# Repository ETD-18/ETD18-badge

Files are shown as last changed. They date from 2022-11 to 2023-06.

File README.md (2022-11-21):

# ETD18-badge
This badge commemorates the ETD18 training group

## Schematic
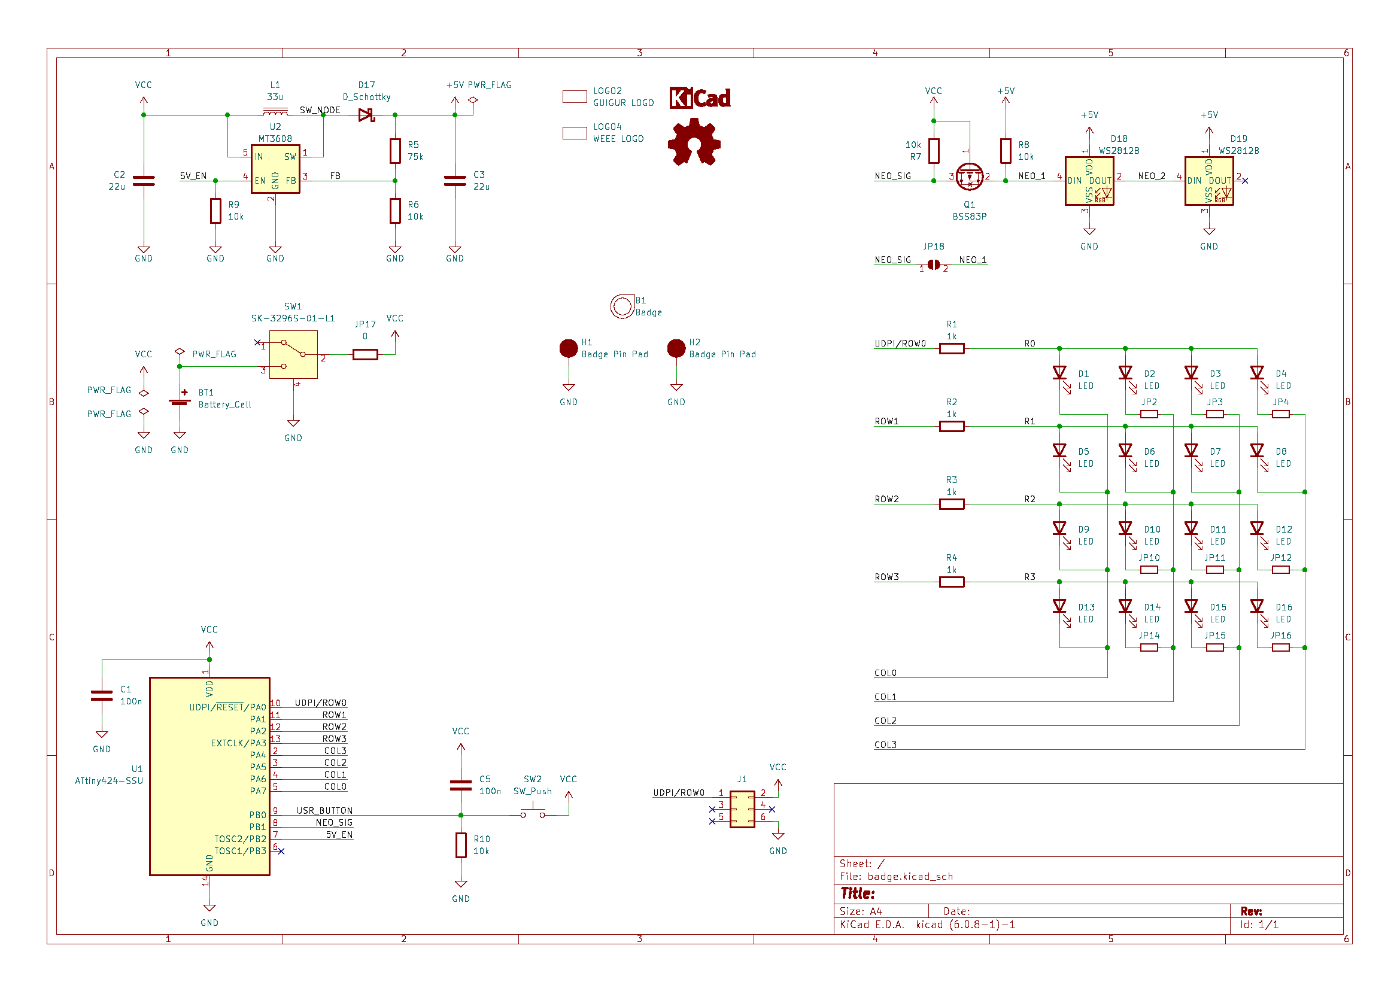
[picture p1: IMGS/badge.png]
schematic schematic of the badge


## Pics
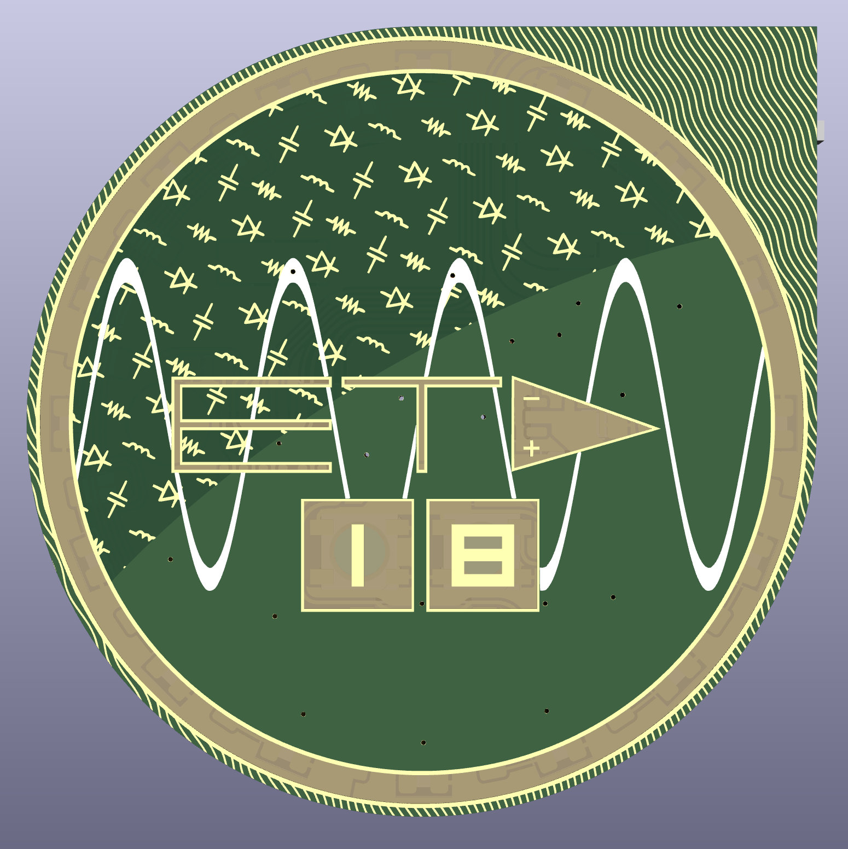
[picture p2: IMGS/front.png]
front front of the badge

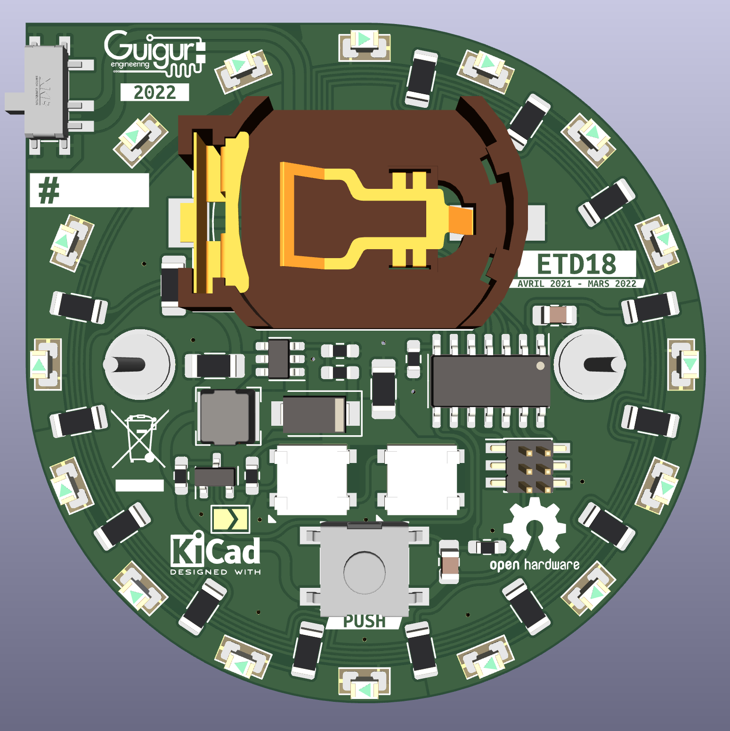
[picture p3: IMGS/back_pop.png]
back back of the badge


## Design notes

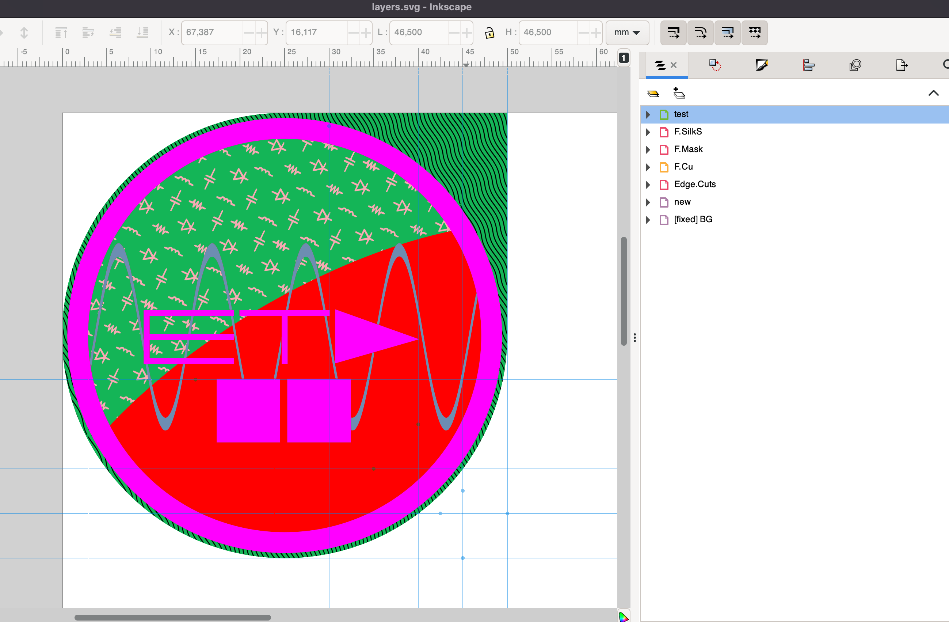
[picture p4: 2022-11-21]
IMGS/inkscape.png

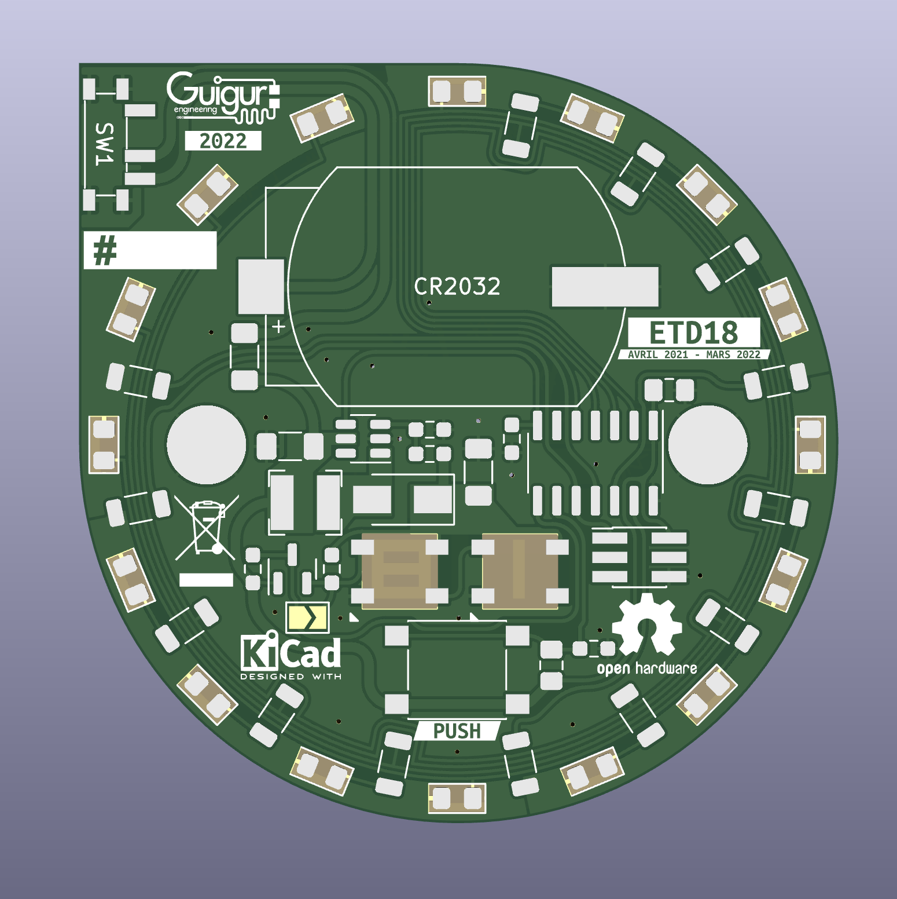
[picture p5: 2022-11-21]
IMGS/back.png

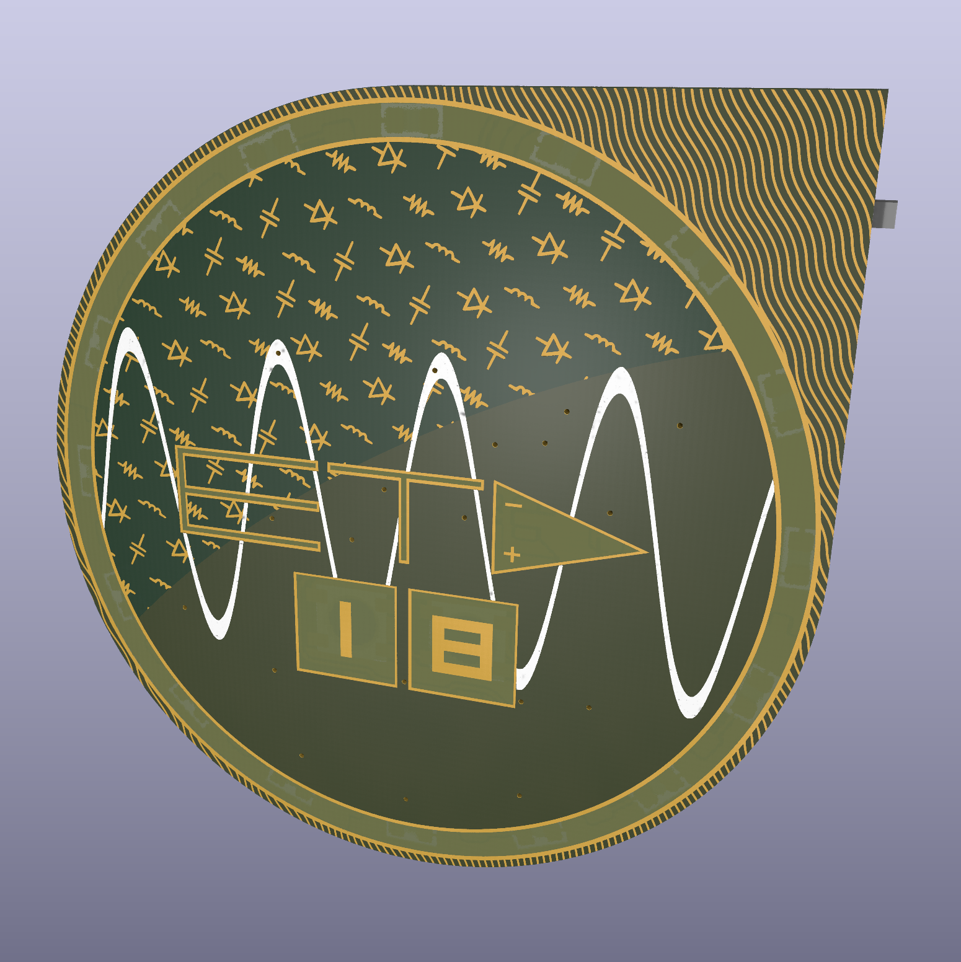
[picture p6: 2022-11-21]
IMGS/front_iso_rayt.png

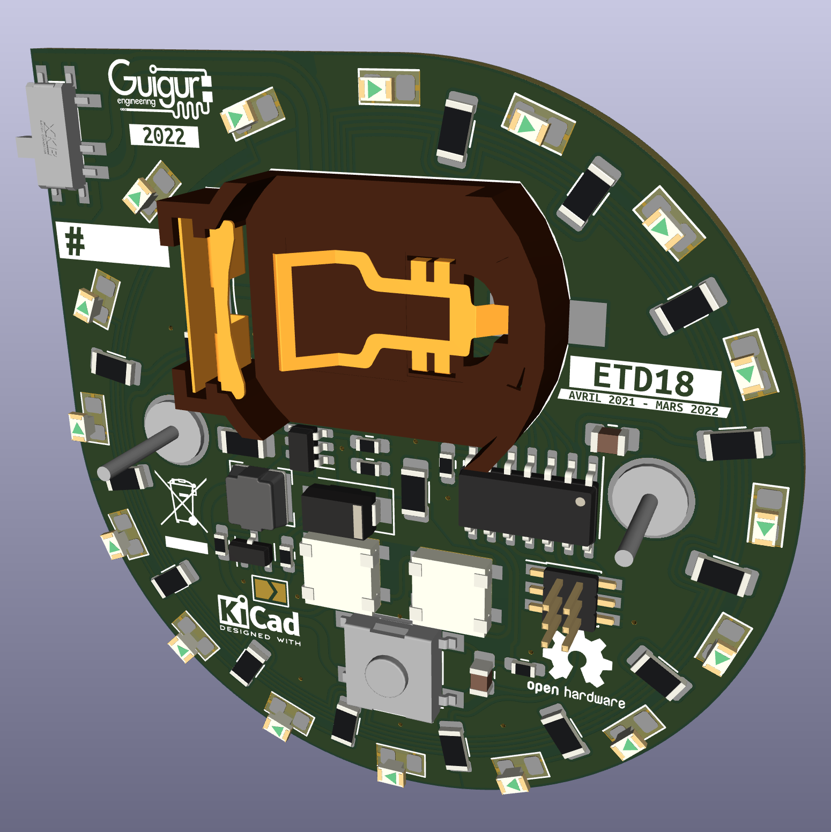
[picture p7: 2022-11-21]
IMGS/back_pop_iso.png

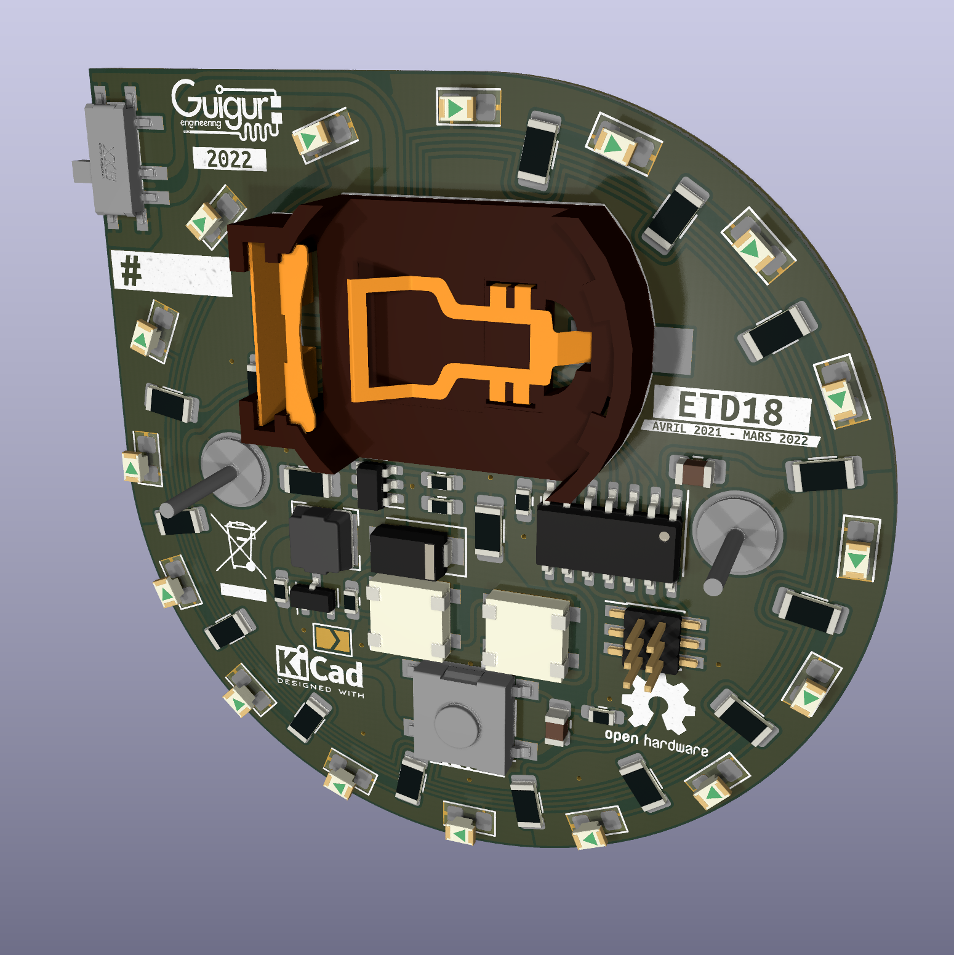
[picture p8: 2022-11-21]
IMGS/back_pop_iso_rayt.png

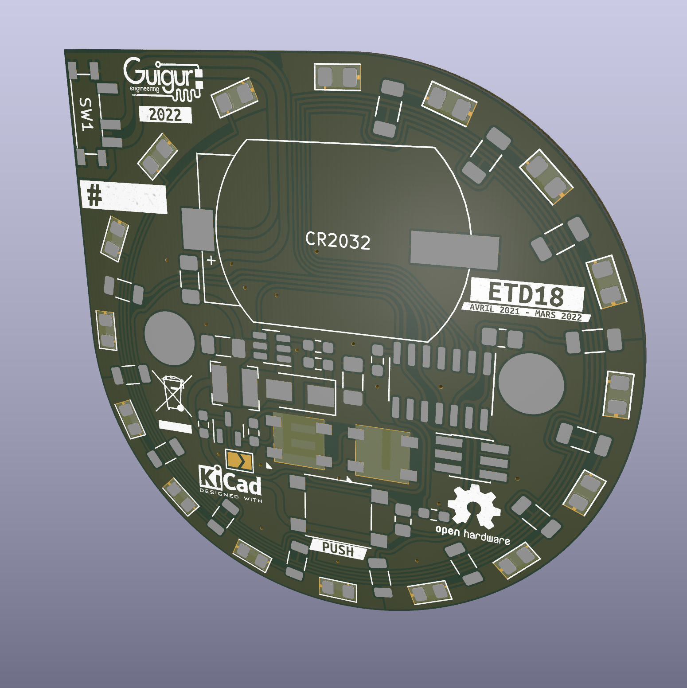
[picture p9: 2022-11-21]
IMGS/back_iso_rayt.png

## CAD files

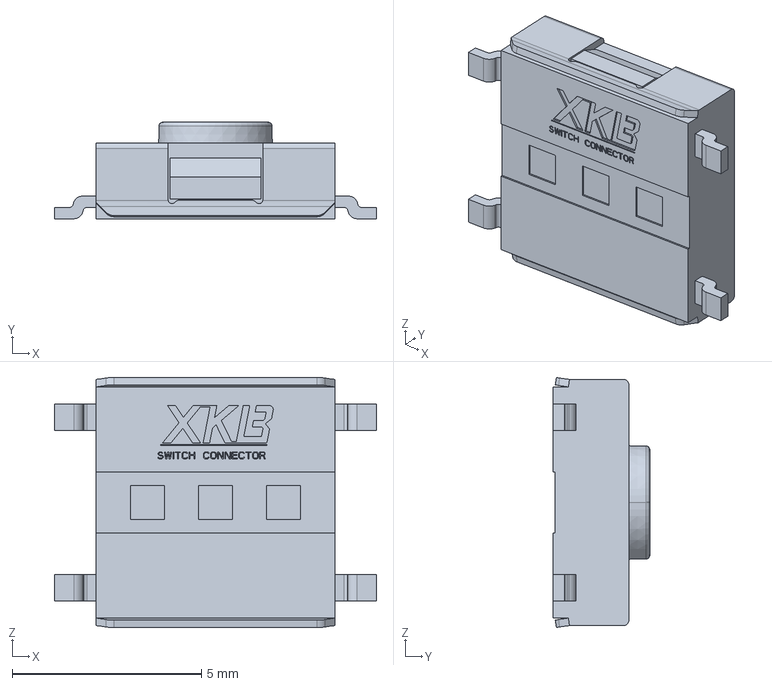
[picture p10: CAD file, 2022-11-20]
badge/step/ts-1157-b-a.stp
8.50 x 2.55 x 6.60 mm

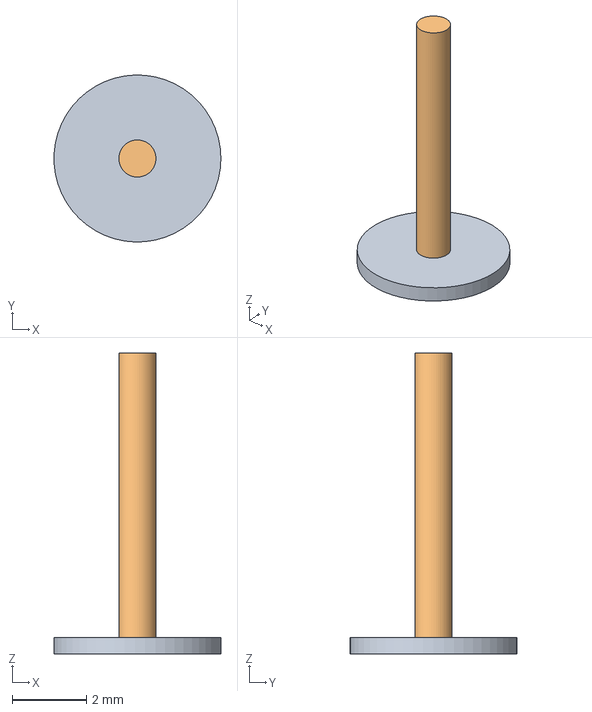
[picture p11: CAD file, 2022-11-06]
badge/step/pin.step
4.50 x 4.50 x 8.11 mm

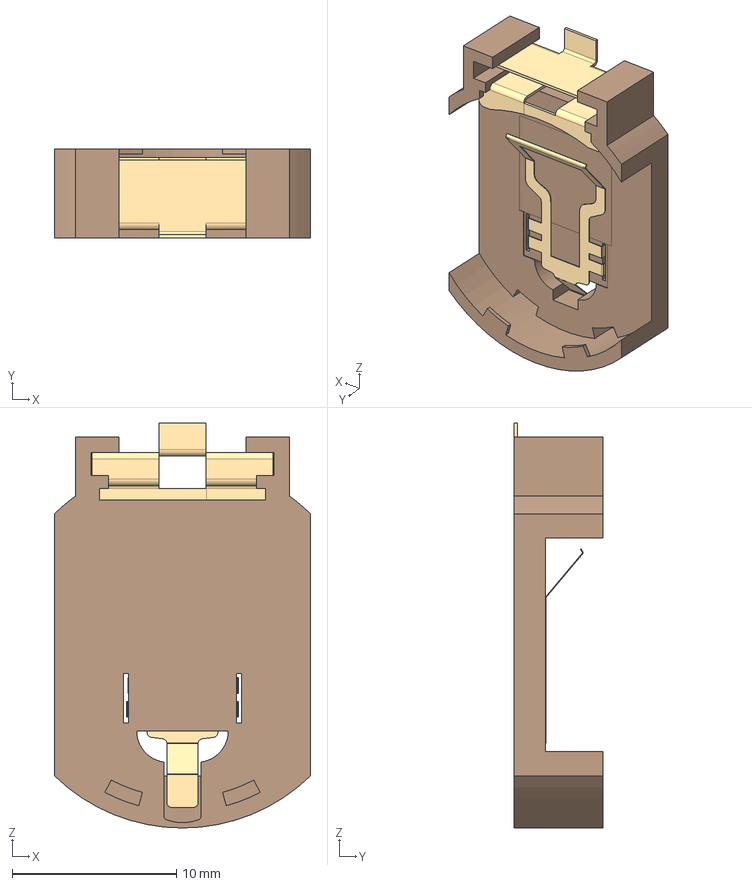
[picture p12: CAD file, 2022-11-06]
badge/step/s8421-45r.stp
15.6 x 5.40 x 24.7 mm

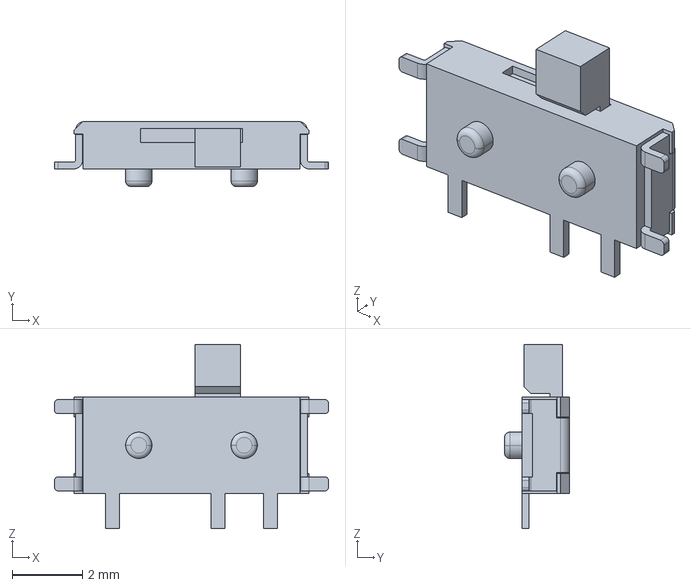
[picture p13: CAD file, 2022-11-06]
badge/step/sk-3296s-01-l1.stp
7.80 x 1.85 x 5.25 mm

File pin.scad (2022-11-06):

cylinder( r = 2.25, h=0.45 );
cylinder( r = 0.5, h=8.11 );

// Written by Marius Kintel <marius@kintel.net>
//
// To the extent possible under law, the author(s) have dedicated all
// copyright and related and neighboring rights to this software to the
// public domain worldwide. This software is distributed without any
// warranty.
//
// You should have received a copy of the CC0 Public Domain
// Dedication along with this software.
// If not, see <http://creativecommons.org/publicdomain/zero/1.0/>.

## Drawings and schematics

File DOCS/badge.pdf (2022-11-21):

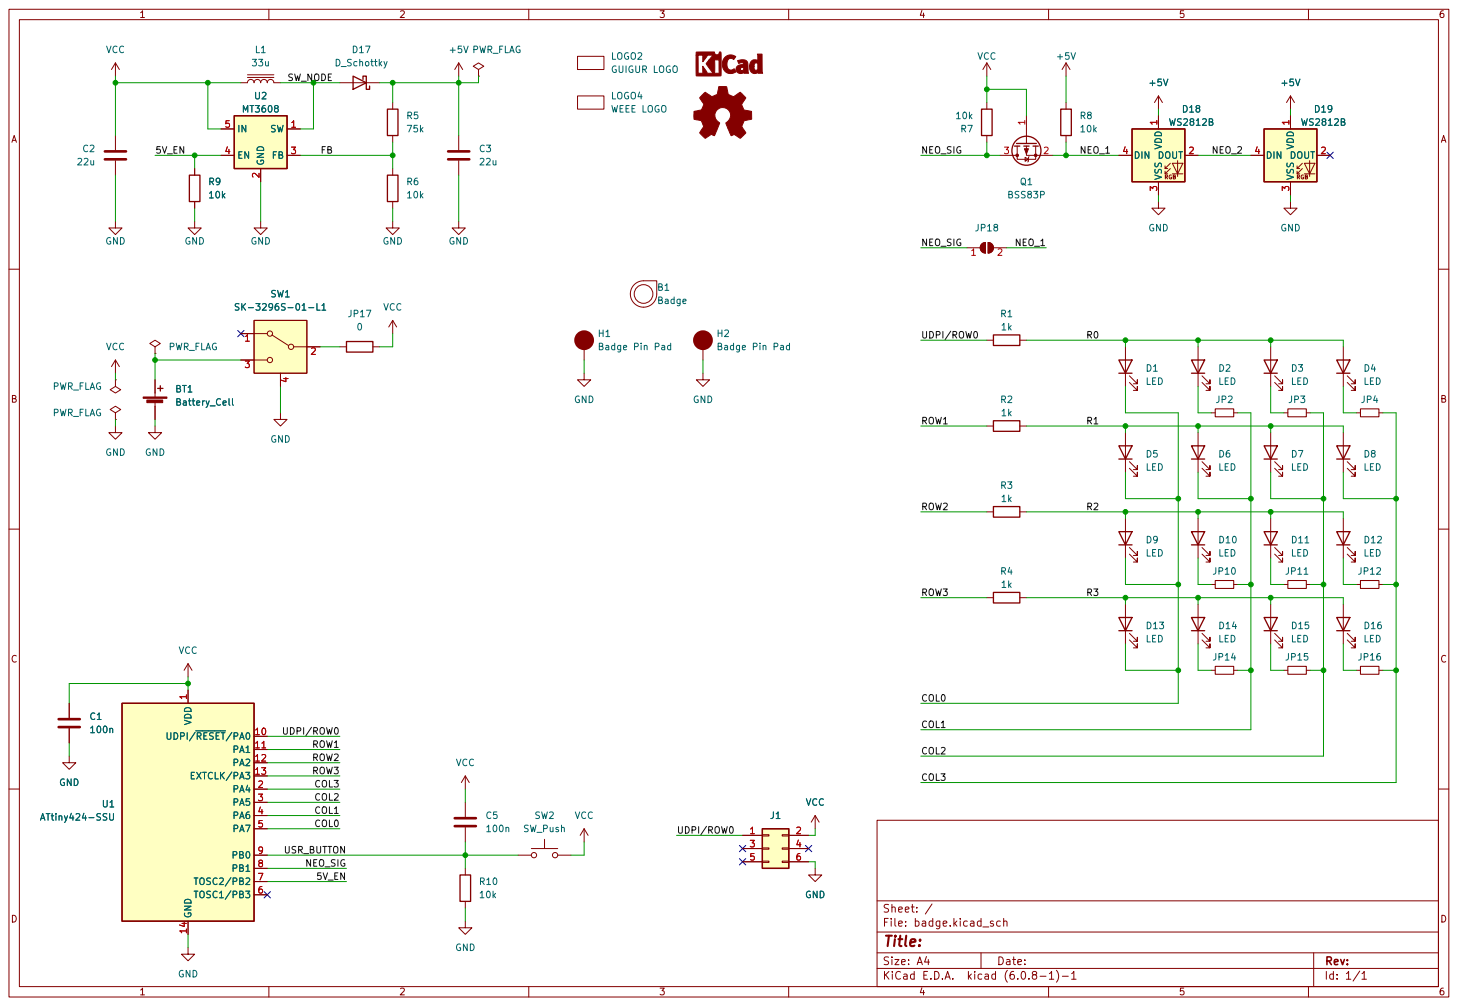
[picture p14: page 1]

1k H2Badge Pin Pad GND GND

1 UDPI/~{RESET}/PA010 PA1 11 PA2 12 EXTCLK/PA3 13 GND 14 PA4 2 PA5 3 PA6 4 PA7 5 TOSC1/PB3 6 TOSC2/PB2 7 PB1 8 PB0 9 GND

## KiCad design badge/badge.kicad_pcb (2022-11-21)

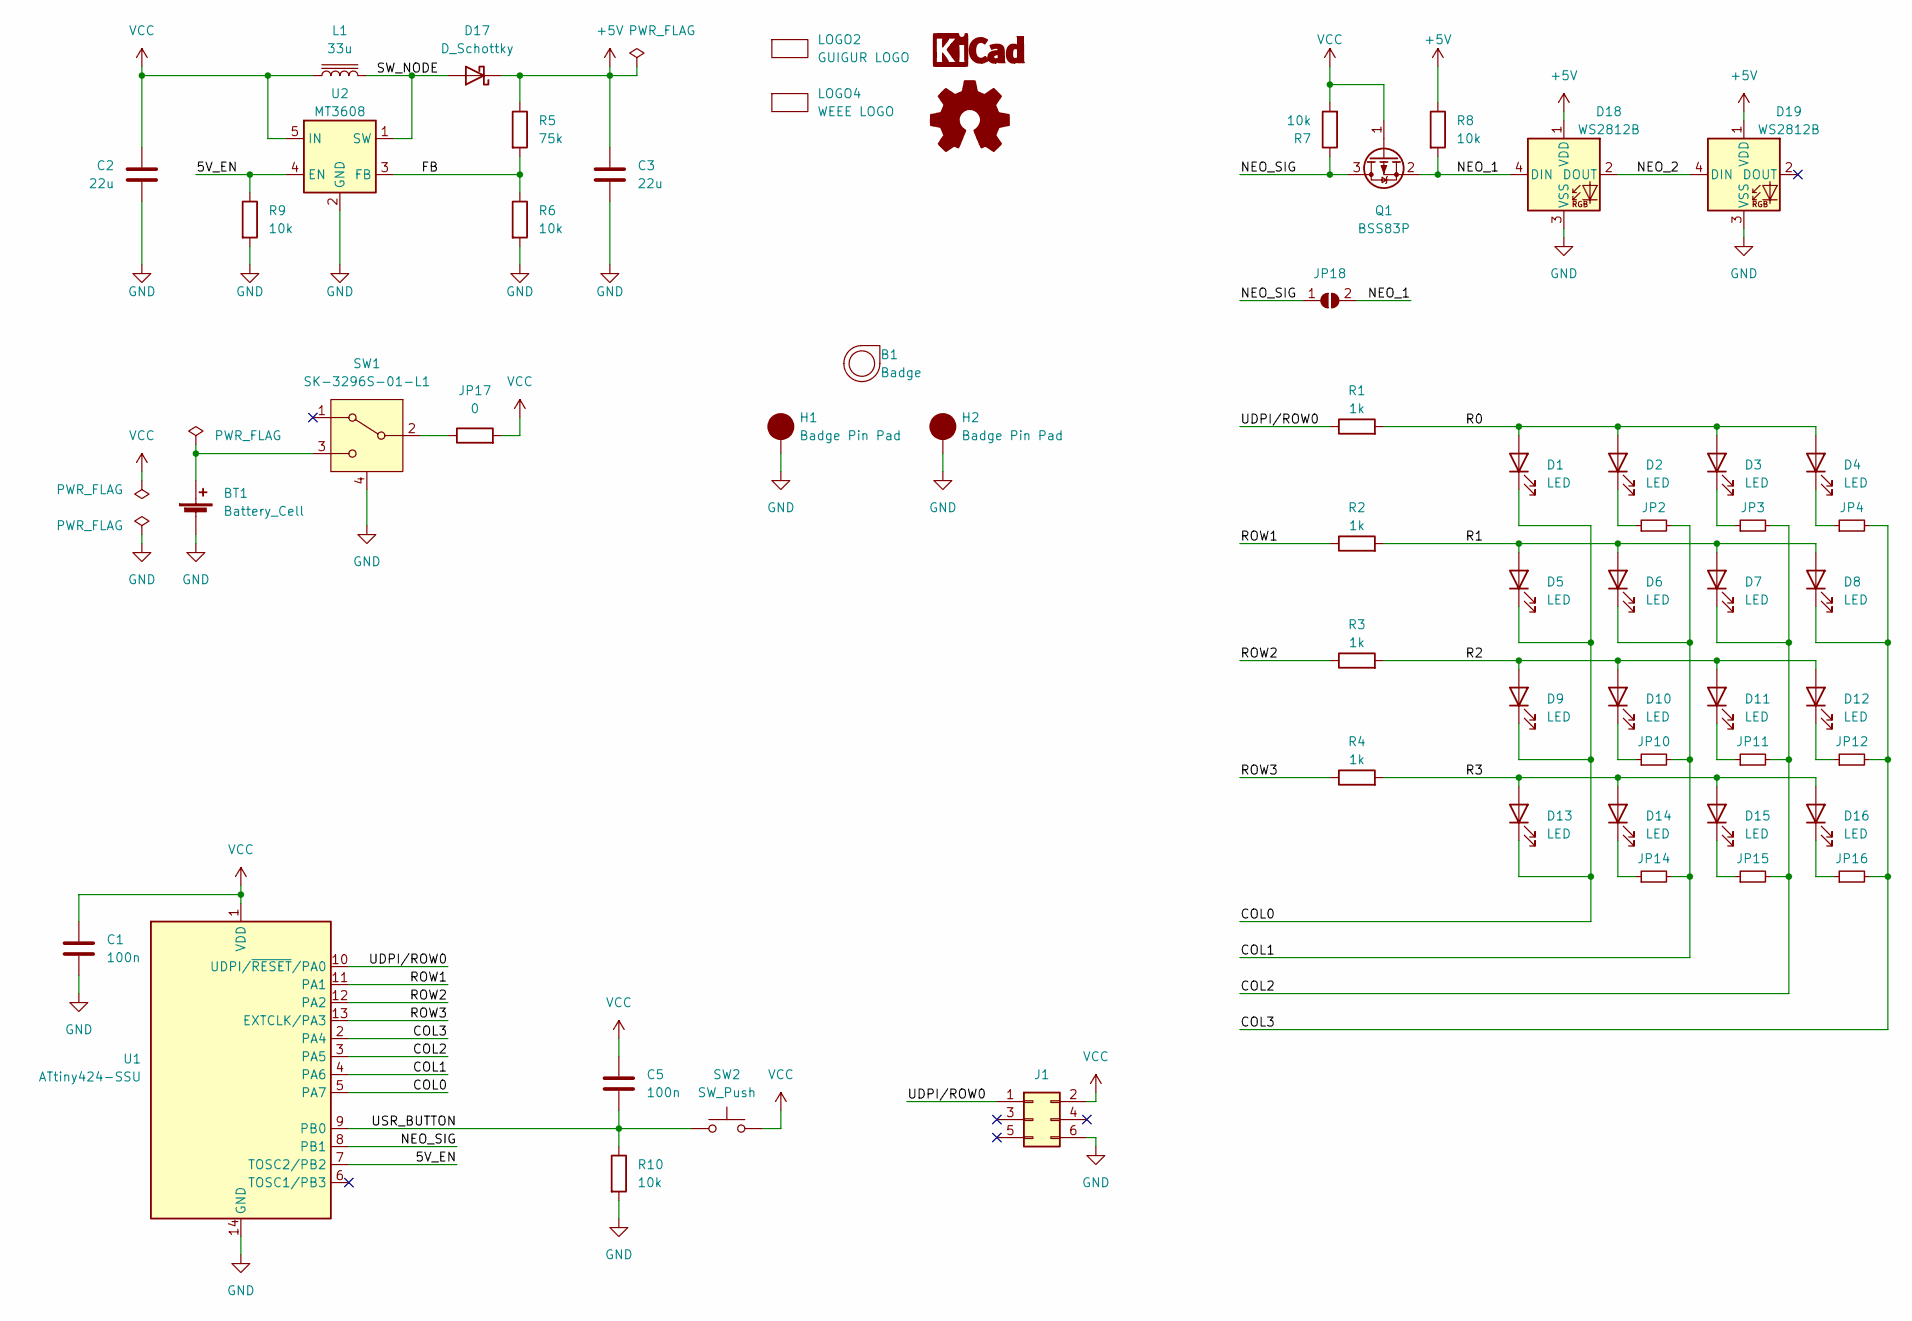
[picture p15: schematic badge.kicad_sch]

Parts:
B1: Badge; layers
BT1: Battery_Cell; cr_2032_holder_S8421-45R
C1, C5: 100n; C_0805_2012Metric_Pad1.18x1.45mm_HandSolder
C2, C3: 22u; R_1206_3216Metric_Pad1.30x1.75mm_HandSolder
D1, D2, D3, D4, D5, D6, D7, D8, D9, D10, D11, D12, D13, D14, D15, D16: LED; LED_0805_2012_badge
D17: D_Schottky; D_SMA
D18, D19: WS2812B; LED_WS2812B_PLCC4_5.0x5.0mm_P3.2mm
H1, H2: Badge Pin Pad; pin_badge
J1: Conn_02x03_Odd_Even; UDPI_connector
JP2, JP3, JP4, JP10, JP11, JP12, JP14, JP15, JP16: 0; R_1206_3216_jumper
JP17: 0; R_1206_3216Metric_Pad1.30x1.75mm_HandSolder
JP18: SolderJumper_2_Open; SolderJumper-2_P1.3mm_Open_TrianglePad1.0x1.5mm
L1: 33u; L_Bourns-SRN4018
LOGO1: Logo_Open_Hardware_Small; OSHW-Logo2_7.3x6mm_SilkScreen
LOGO2: GUIGUR LOGO; guigur_engineering_extra_small_logo
LOGO3: KiCAD LOGO Small; kicad_design_with_7.5mm
LOGO4: WEEE LOGO; WEEE-Logo_4.2x6mm_SilkScreen
Q1: BSS83P; SOT-23
R1, R2, R3, R4: 1k; R_1206_3216_jumper
R5: 75k; R_0603_1608Metric_Pad0.98x0.95mm_HandSolder
R6, R7, R8, R9, R10: 10k; R_0603_1608Metric_Pad0.98x0.95mm_HandSolder
SW1: SK-3296S-01-L1; sk-3296s-01-l1
SW2: SW_Push; SW_Push_1P1T_NO_6x6mm_H9.5mm
U1: ATtiny424-SSU; SOIC-14_3.9x8.7mm_P1.27mm
U2: MT3608; SOT-23-6

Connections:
+5V: C3.1, D17.1 (K), D18.1 (VDD), D19.1 (VDD), R5.1, R8.1
/5V_EN: R9.1, U1.7 (TOSC2/PB2), U2.4 (EN)
/COL0: D1.1 (K), D5.1 (K), D9.1 (K), D13.1 (K), U1.5 (PA7)
/COL1: D6.1 (K), JP2.2, JP10.2, JP14.2, U1.4 (PA6)
/COL2: D7.1 (K), JP3.2, JP11.2, JP15.2, U1.3 (PA5)
/COL3: D8.1 (K), JP4.2, JP12.2, JP16.2, U1.2 (PA4)
/FB: R5.2, R6.1, U2.3 (FB)
/NEO_1: D18.4 (DIN), JP18.2 (B), Q1.2 (S), R8.2
/NEO_2: D18.2 (DOUT), D19.4 (DIN)
/NEO_SIG: JP18.1 (A), Q1.3 (D), R7.1, U1.8 (PB1)
/R0: D1.2 (A), D2.2 (A), D3.2 (A), D4.2 (A), R1.2
/R1: D5.2 (A), D6.2 (A), D7.2 (A), D8.2 (A), R2.2
/R2: D9.2 (A), D10.2 (A), D11.2 (A), D12.2 (A), R3.2
/R3: D13.2 (A), D14.2 (A), D15.2 (A), D16.2 (A), R4.2
/ROW1: R2.1, U1.11 (PA1)
/ROW2: R3.1, U1.12 (PA2)
/ROW3: R4.1, U1.13 (EXTCLK/PA3)
/SW_NODE: D17.2 (A), L1.2, U2.1 (SW)
/UDPI/ROW0: J1.1, R1.1, U1.10 (UDPI/~RESET/PA0)
/USR_BUTTON: C5.2, R10.1, SW2.1, U1.9 (PB0)
GND: BT1.2 (-), C1.2, C2.2, C3.2, D18.3 (VSS), D19.3 (VSS), H1.1, H2.1, J1.6, R6.2, R9.2, R10.2, SW1.4 (CHASSIS), U1.14 (GND), U2.2 (GND)
unnamed: BT1.1 (+), SW1.3 (C)
unnamed: D2.1 (K), JP2.1
unnamed: D3.1 (K), JP3.1
unnamed: D4.1 (K), JP4.1
unnamed: D10.1 (K), JP10.1
unnamed: D11.1 (K), JP11.1
unnamed: D12.1 (K), JP12.1
unnamed: D14.1 (K), JP14.1
unnamed: D15.1 (K), JP15.1
unnamed: D16.1 (K), JP16.1
unnamed: JP17.1, SW1.2 (B)
VCC: C1.1, C2.1, C5.1, J1.2, JP17.2, L1.1, Q1.1 (G), R7.2, SW2.2, U1.1 (VDD), U2.5 (IN)

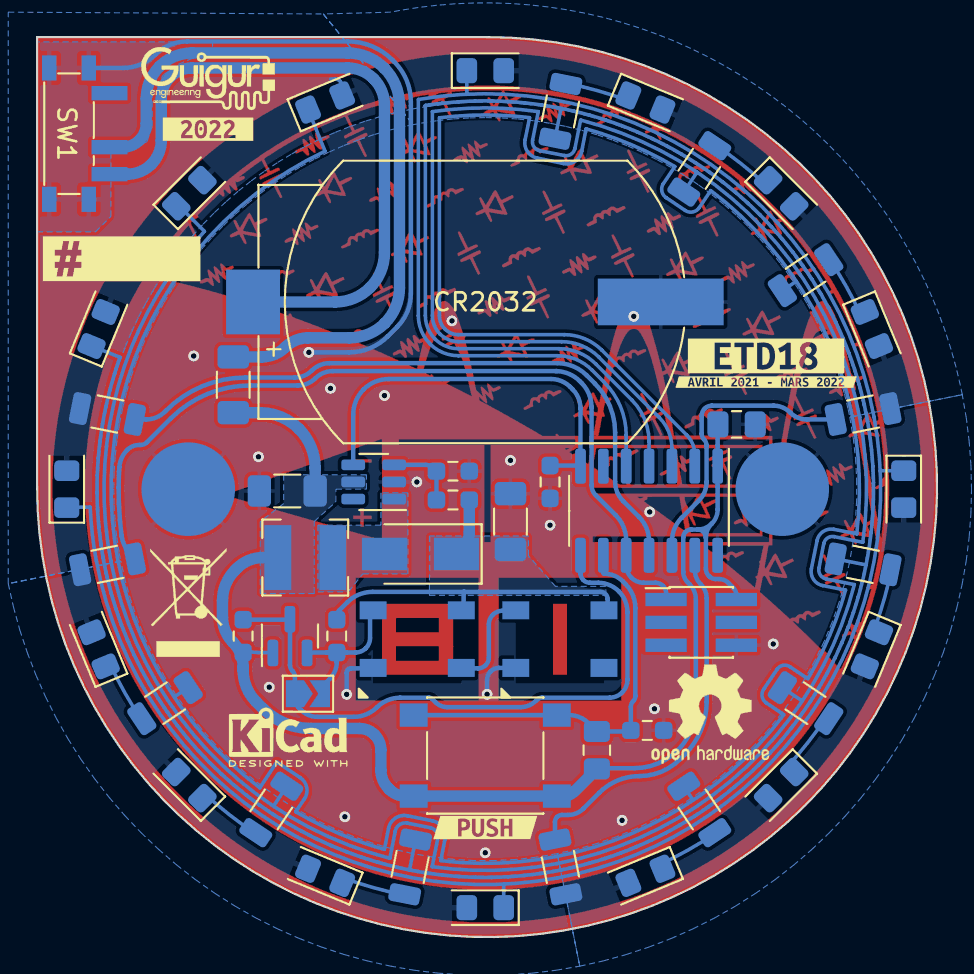
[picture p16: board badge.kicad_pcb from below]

Board: 2 copper layers, 50.0 x 50.0 mm, 64 parts (63 on the bottom side), 33 nets.

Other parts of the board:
kibuzzard-637A9AEB: G***; kibuzzard-637A9AEB
kibuzzard-637A9DDD: G***; kibuzzard-637A9DDD
kibuzzard-637A9580: G***; kibuzzard-637A9580
kibuzzard-637A9837: G***; kibuzzard-637A9837
kibuzzard-637A9899: G***; kibuzzard-637A9899

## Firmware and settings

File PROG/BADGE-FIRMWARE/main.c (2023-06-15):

/*
 * main.c
 *
 * Created: 8/6/2022 3:13:30 PM
 *  Author: guigur
 */ 

//#include <xc.h>
#include <avr/io.h>
#include <avr/interrupt.h>
#include <util/delay.h>
#include <util/twi.h>

uint8_t rows[] = { 0x02, 0x01, 0x08, 0x04 }; //R1 R0 R3 R2
uint8_t cols[] = { 0xe0, 0xd0, 0xb0, 0x70 };

typedef union cg {
	uint8_t brg[3];
	uint32_t col;
} colorGrad_t;

//uint32_t color = 0xFF0000; //BRG
uint8_t colorA[] = { 0x00, 0xff, 0xff };
#define NEOONE 	PORTB.OUT = 0xff;PORTB.OUT = 0xff;PORTB.OUT = 0xff;PORTB.OUT = 0xff;PORTB.OUT = 0xff;PORTB.OUT = 0xff;PORTB.OUT = 0x00; PORTB.OUT = 0x00; PORTB.OUT = 0x00;
#define NEOZERO PORTB.OUT = 0xff;PORTB.OUT = 0xff;PORTB.OUT = 0xff;PORTB.OUT = 0x00;PORTB.OUT = 0x00;PORTB.OUT = 0x00; PORTB.OUT = 0x00; PORTB.OUT = 0x00;

//#define NEOONE 	PORTB.OUT = 0xff;PORTB.OUT = 0xff;PORTB.OUT = 0xff;PORTB.OUT = 0xff;PORTB.OUT = 0xff;PORTB.OUT = 0xff;PORTB.OUT = 0xff;PORTB.OUT = 0x00;PORTB.OUT = 0x00;PORTB.OUT = 0x00;PORTB.OUT = 0x00;PORTB.OUT = 0x00;PORTB.OUT = 0x00;
//#define NEOZERO PORTB.OUT = 0xff;PORTB.OUT = 0xff;PORTB.OUT = 0xff;PORTB.OUT = 0xff;PORTB.OUT = 0x00;PORTB.OUT = 0x00;PORTB.OUT = 0x00;PORTB.OUT = 0x00;PORTB.OUT = 0x00;PORTB.OUT = 0x00;PORTB.OUT = 0x00;PORTB.OUT = 0x00;

void d(uint16_t val)
{
	for(uint16_t i = 0; i < val; i++) {}
}

void ringAnnim()
{
		//col => e d b 7 MSB
		//row => 2 4 8 LSB
		for (uint8_t r = 0; r < sizeof(rows); r++)
		{
			for (uint8_t c = 0; c < sizeof(cols); c++)
			{
				PORTA.OUT = rows[r] + cols[c];
				_delay_ms(1000);
			}
		}
}

void neopix(uint32_t color)
{
	for(uint8_t i = 0; i < 24; i++)
	{
		if (color & 0x01)
		{
			NEOONE;
		}
		else
		{
			NEOZERO;
		}
		color = color >> 1;
	}
}

/*
ISR(TCA0_OVF_vect)
{
	TCA0.SINGLE.INTFLAGS = TCA_SINGLE_OVF_bm;
	PORTB.OUT = 0;
	PORTB.OUT = 0xff;
}
*/

void timerInit()
{
	TCA0.SINGLE.INTCTRL = 0 << TCA_SINGLE_CMP0_bp
	| 0 << TCA_SINGLE_CMP1_bp
	| 0 << TCA_SINGLE_CMP2_bp
	| 1 << TCA_SINGLE_OVF_bp;
	
	TCA0.SINGLE.PER = 1;
	
	TCA0.SINGLE.CTRLA = TCA_SINGLE_CLKSEL_DIV1_gc
	| 1 << TCA_SINGLE_ENABLE_bp;	
}

typedef enum  { REDO, GREENO, BLUEO } colorStates_t;
typedef struct { colorStates_t s; uint8_t hex; } colorChan_t;
	
colorStates_t state = BLUEO;
//uint8_t dir = 1;
colorGrad_t c;
	

colorStates_t stateMinus(colorStates_t currentState)
{
	if (currentState == REDO)
		return (BLUEO);
	else if (currentState == GREENO) 
		return (REDO);
	else if (currentState == BLUEO) 
		return (GREENO);
}

void colorRoutine(colorChan_t *cc)
{
	//on estime red
	if (state == stateMinus(cc->s)) //BLUEO)
	{
		if (cc->hex >= 255)
		{
			state = cc->s;
		}
		else
		{
			cc->hex = cc->hex + 1;
		}
	}
	else if (state == cc->s)
	{
		cc->hex = cc->hex - 1;
	}
}
colorChan_t ccred = { REDO, 0 };
	colorChan_t ccblue = { BLUEO, 0 };
	colorChan_t ccgreen = { GREENO, 0 };
void colorMania()
{
	

	colorRoutine(&ccred);
	colorRoutine(&ccblue);
	colorRoutine(&ccgreen);
	c.brg[0] = ccblue.hex;
	c.brg[1] = ccred.hex;
	c.brg[2] = ccgreen.hex;

	// ccred.hex, ccgreen.hex};
}

int main(void)
{
	CCP = 0xD8;
	CLKCTRL.MCLKCTRLB = 0x00;
	
	PORTA.DIR = 0xFF; //all outs
	PORTB.DIR = 0xFF; //all ins
	
	timerInit();
	cli();
	//sei();






 /* Configure SW0 as input */
 PORTB.DIRCLR = PIN0_bm;
 int a = PIN0_bm;
 /*Enable internal pull up for SW0*/
 //PORTB.PIN0CTRL = PORT_PULLUPEN_bm;

 while (1)
 {
	/* Check the status of SW0 */
	/* 0: Pressed */
	if (!(PORTB.IN & (PIN0_bm)))
	{
		colorMania();
		/* LED0 off */
		//PORTA.DIR = 0xFF; //all outs
		//ringAnnim();
		//PORTA.DIRCLR = 0x00;
	}
	/* 1: Released */
	else
	{
		/* LED0 on */
	}
	 _delay_ms(500);
}



	//PORTA.OUT = 0x0F;
	while(1)
    {

			//ringAnnim();
		
		//neopix(c.col);
		//neopix(0xff0000);
	  //neopix();
	  		//colorMania();



	}
	return (0);
}

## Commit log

2022-11-06 schematic nearlly finished + new design on inkscape
    [badge.kicad_pcb, badge.kicad_sch, pin.FCStd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]
2022-11-13 wip schematic finished and slow fill on pcb. test before removing all tracks
    [badge.kicad_sch]
2022-11-19 finished the led matrix
    [badge.kicad_sch]
2022-11-20 routing finished. need to update one last time the badge's footprint tho
    [badge.kicad_pcb, badge.kicad_sch]
2022-11-20 updated the footprint of the badge and corrected the button footprint
    [badge-B_Cu.gbr, badge-B_Mask.gbr, badge-B_Paste.gbr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]
2022-11-21 pcb finished and ready to be ordered
    [badge-B_Cu.gbr, badge-B_Mask.gbr, badge-B_Silkscreen.gbr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]
2022-11-21 added schematic
    [badge.kicad_sch]
2022-11-21 small correction
    [badge.kicad_pcb]
2023-01-06 debugging wip
    [badge-B_Cu.gbr, badge-B_Mask.gbr, badge-B_Paste.gbr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]
